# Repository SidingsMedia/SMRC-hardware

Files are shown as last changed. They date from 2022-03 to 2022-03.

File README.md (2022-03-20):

<!-- 
SPDX-FileCopyrightText: Copyright (c) 2021 Matthew Nickson 

SPDX-License-Identifier: MIT
-->
# Hardware
      

This repository contains all of the schematics and PCB files for Sidings
Media Railway Controller. 

## Main Control Board

This is the main component of the SMRC system. It provides a bridge
between the control nodes and the user as well as handling all of the
railway control logic.

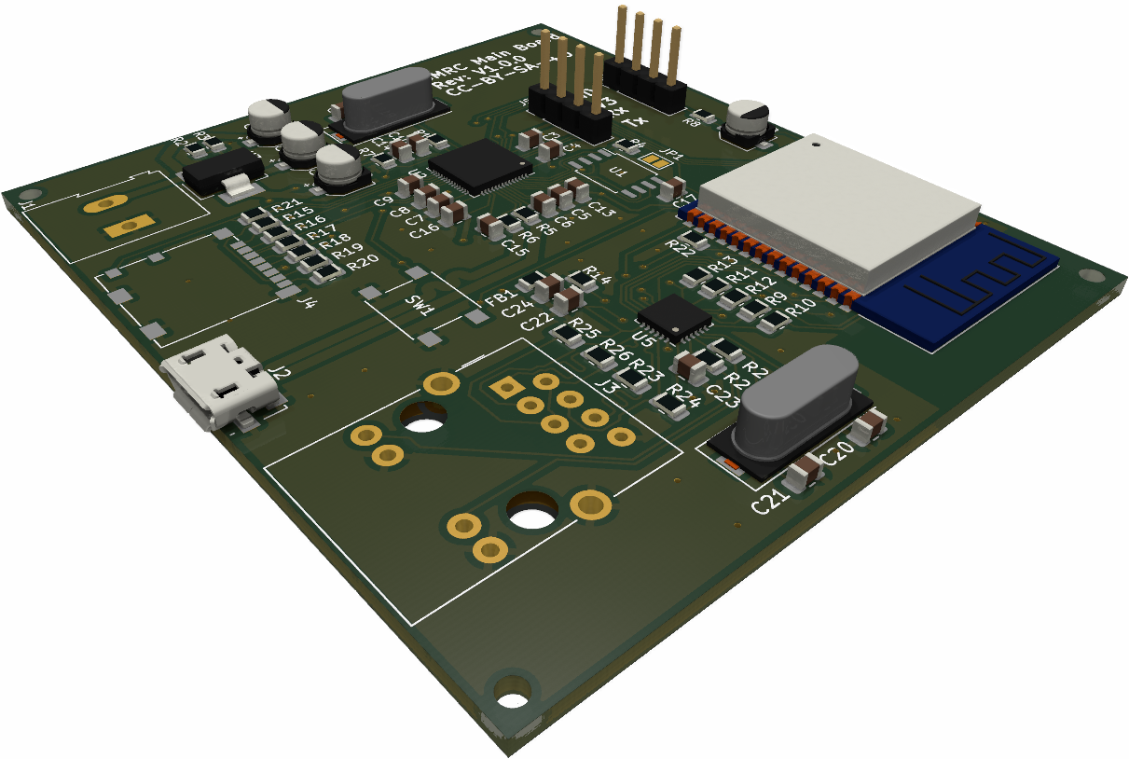
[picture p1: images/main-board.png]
3D render of main control PCB


## Speed Control Board

This is one of the nodes that helps to control the railway. It provides
power and controls the speed of a train on the tracks

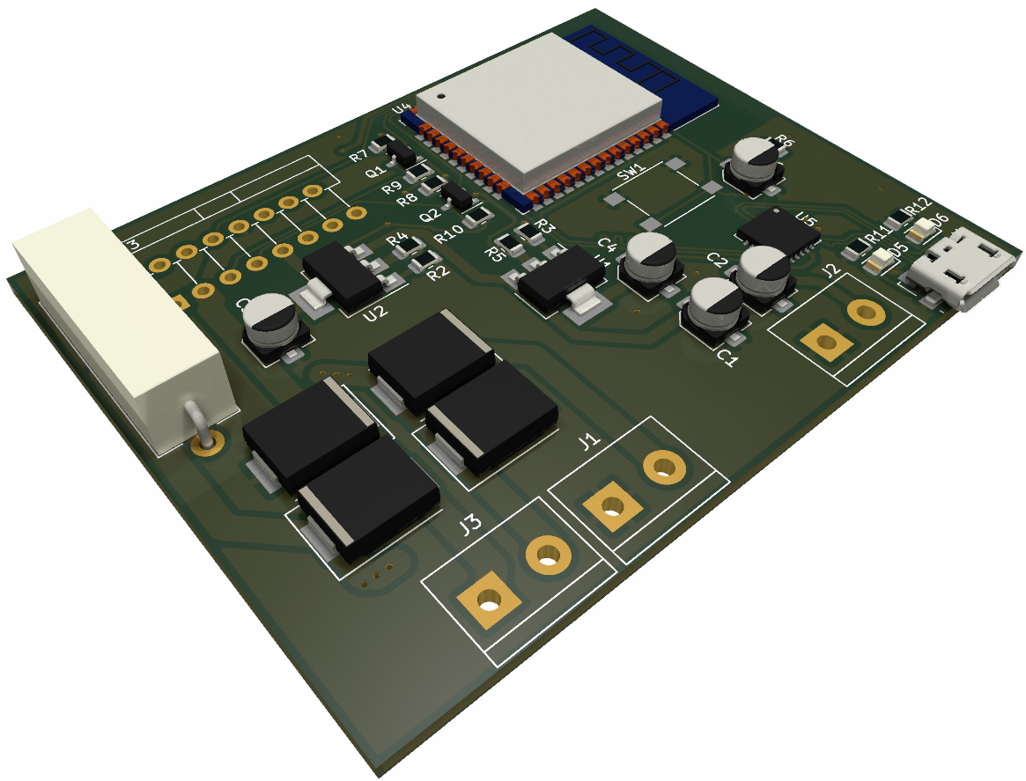
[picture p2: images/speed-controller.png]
3D render of speed control PCB


## Relay Board

This node controls isolation sections in your track allowing for
multiple trains to be on the same line without having to use DCC. It has
8 channels allowing for up to 8 seperate isolation sections to be
controlled from one speed controller.

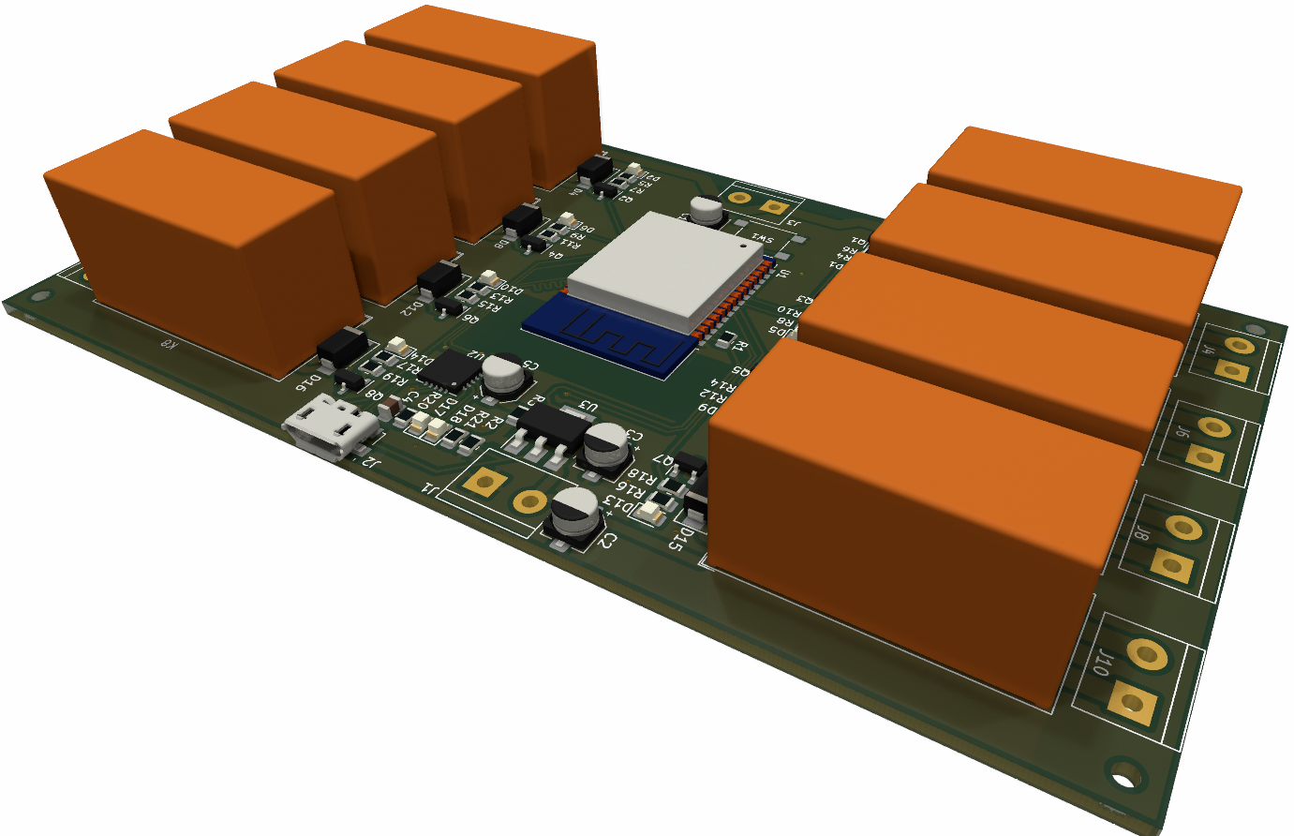
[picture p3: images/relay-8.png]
3D render of 8 channel relay PCB


# Licence
This repo uses the [REUSE](https://reuse.software) standard in order to communicate the correct licence for the file. For those unfamiliar with the standard the licence for each file can be found in one of three places. The licence will either be in a comment block at the top of the file, in a `.license` file with the same name as the file, or in the dep5 file located in the `.reuse` directory. If you are unsure of the licencing terms please contact [contact@sidingsmedia.com](mailto:contact@sidingsmedia.com?subject=SMRC%20Licence). All files committed to this repo must contain valid licencing information or the pull request can not be accepted.

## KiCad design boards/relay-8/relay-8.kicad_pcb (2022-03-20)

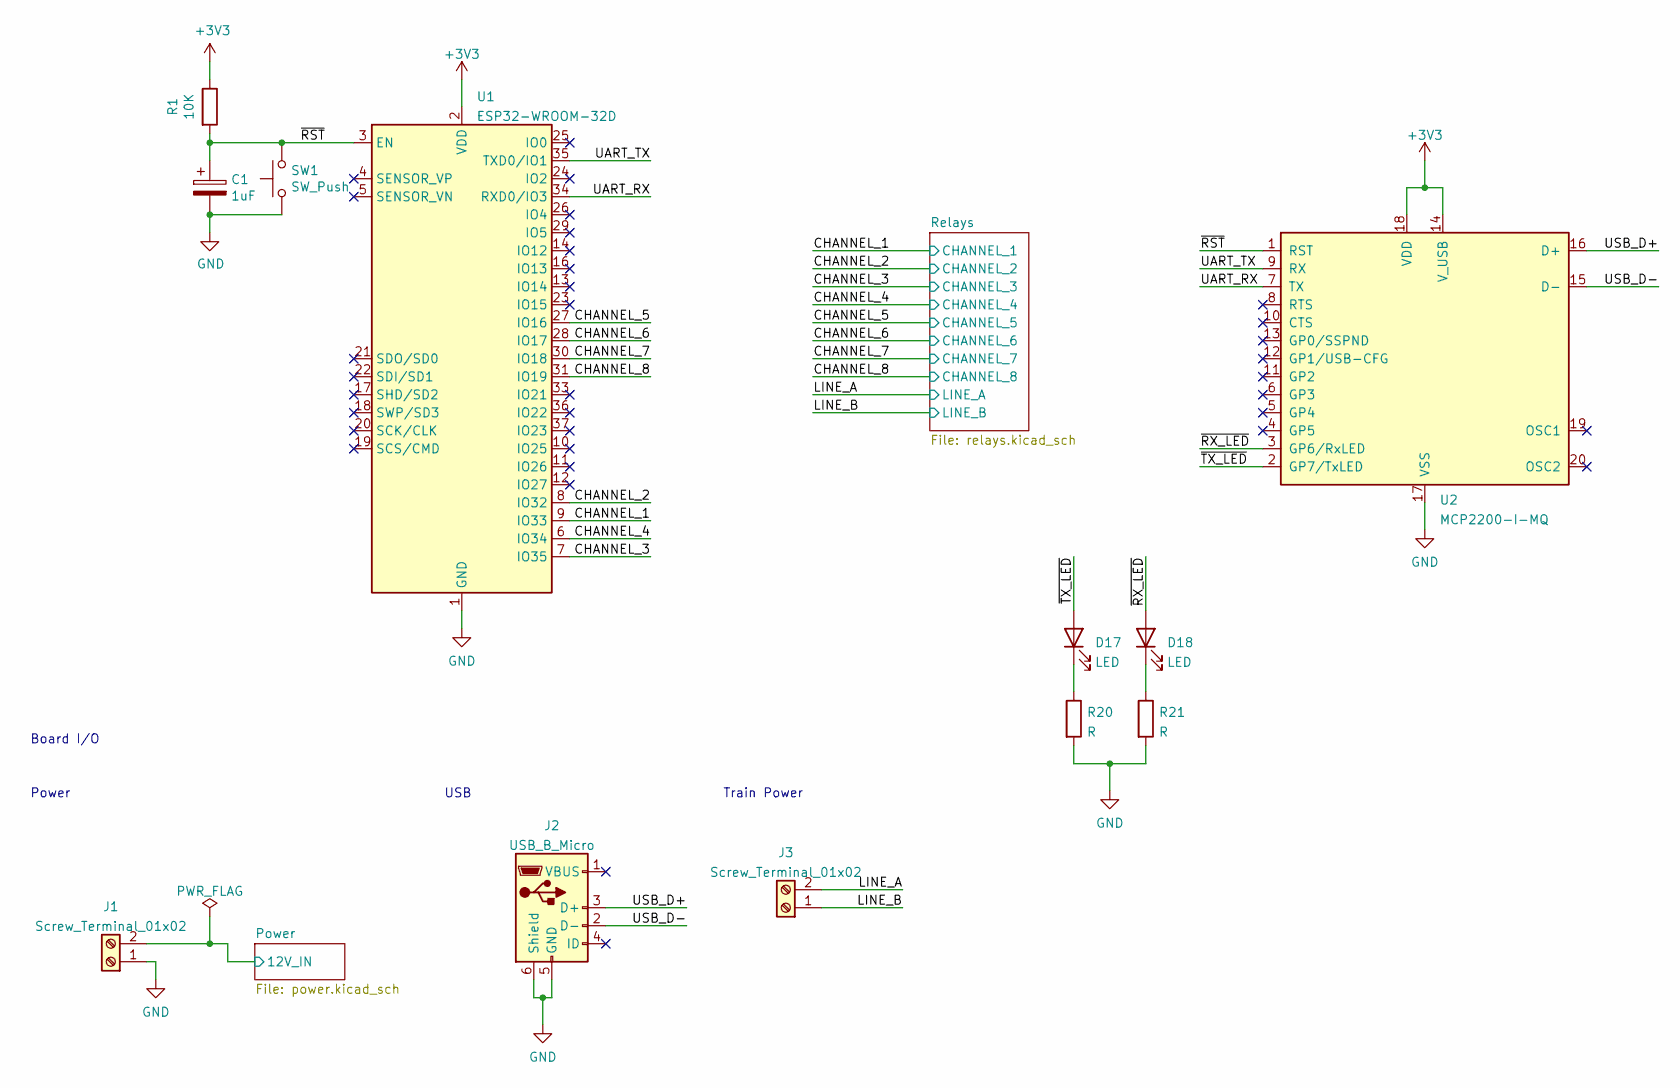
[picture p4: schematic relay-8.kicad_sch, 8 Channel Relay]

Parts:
C1: 1uF; CP_Elec_4x3
D17, D18: LED; LED_0805_2012Metric
J1, J3: Screw_Terminal_01x02; TerminalBlock_bornier-2_P5.08mm
J2: USB_B_Micro; USB_Micro-B_Molex_47346-0001
R1: 10K; R_0805_2012Metric
R20, R21: R; R_0805_2012Metric
SW1: SW_Push; SW_Push_1P1T_NO_6x6mm_H9.5mm
U1: ESP32-WROOM-32D; ESP32-WROOM-32
U2: MCP2200-I-MQ; QFN-20-1EP_5x5mm_P0.65mm_EP3.35x3.35mm

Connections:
+3V3: R1.1, U1.2 (VDD), U2.14 (V_USB), U2.18 (VDD); also elsewhere on the board
+12V: J1.2; also elsewhere on the board
/CHANNEL_1: U1.9 (IO33); also elsewhere on the board
/CHANNEL_2: U1.8 (IO32); also elsewhere on the board
/CHANNEL_3: U1.7 (IO35); also elsewhere on the board
/CHANNEL_4: U1.6 (IO34); also elsewhere on the board
/CHANNEL_5: U1.27 (IO16); also elsewhere on the board
/CHANNEL_6: U1.28 (IO17); also elsewhere on the board
/CHANNEL_7: U1.30 (IO18); also elsewhere on the board
/CHANNEL_8: U1.31 (IO19); also elsewhere on the board
/LINE_A: J3.2; also elsewhere on the board
/LINE_B: J3.1; also elsewhere on the board
/UART_RX: U1.34 (RXD0/IO3), U2.7 (TX)
/UART_TX: U1.35 (TXD0/IO1), U2.9 (RX)
/USB_D+: J2.3 (D+), U2.16 (D+)
/USB_D-: J2.2 (D-), U2.15 (D-)
/~RST: C1.1, R1.2, SW1.2, U1.3 (EN), U2.1 (RST)
/~RX_LED: D18.2 (A), U2.3 (GP6/RxLED)
/~TX_LED: D17.2 (A), U2.2 (GP7/TxLED)
GND: C1.2, J1.1, J2.5 (GND), J2.6 (Shield), R20.2, R21.2, SW1.1, U1.1 (GND), U1.15 (GND), U1.38 (GND), U1.39 (GND), U2.17 (VSS); also elsewhere on the board
unnamed: D17.1 (K), R20.1
unnamed: D18.1 (K), R21.1

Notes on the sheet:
Train Power
Board I/O
Power
USB

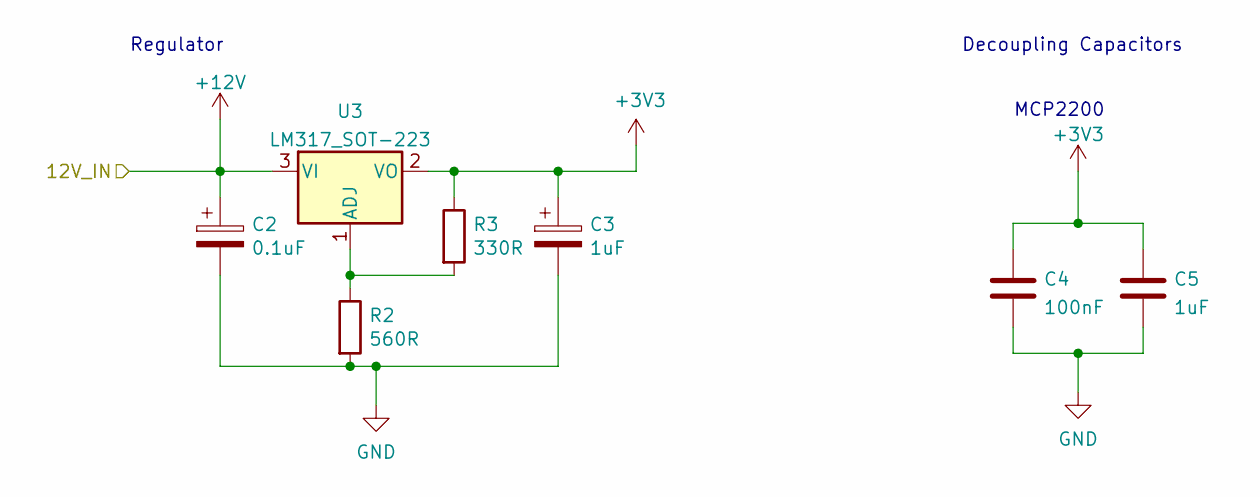
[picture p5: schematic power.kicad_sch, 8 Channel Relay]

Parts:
C2: 0.1uF; CP_Elec_4x3
C3, C5: 1uF; CP_Elec_4x3
C4: 100nF; C_0805_2012Metric
R2: 560R; R_0805_2012Metric
R3: 330R; R_0805_2012Metric
U3: LM317_SOT-223; SOT-223-3_TabPin2

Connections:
+3V3: C3.1, C4.1, C5.1, R3.1, U3.2 (VO); also elsewhere on the board
+12V: C2.1, U3.3 (VI); also elsewhere on the board
GND: C2.2, C3.2, C4.2, C5.2, R2.2; also elsewhere on the board
unnamed: R2.1, R3.2, U3.1 (ADJ)

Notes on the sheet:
Regulator
Decoupling Capacitors
MCP2200

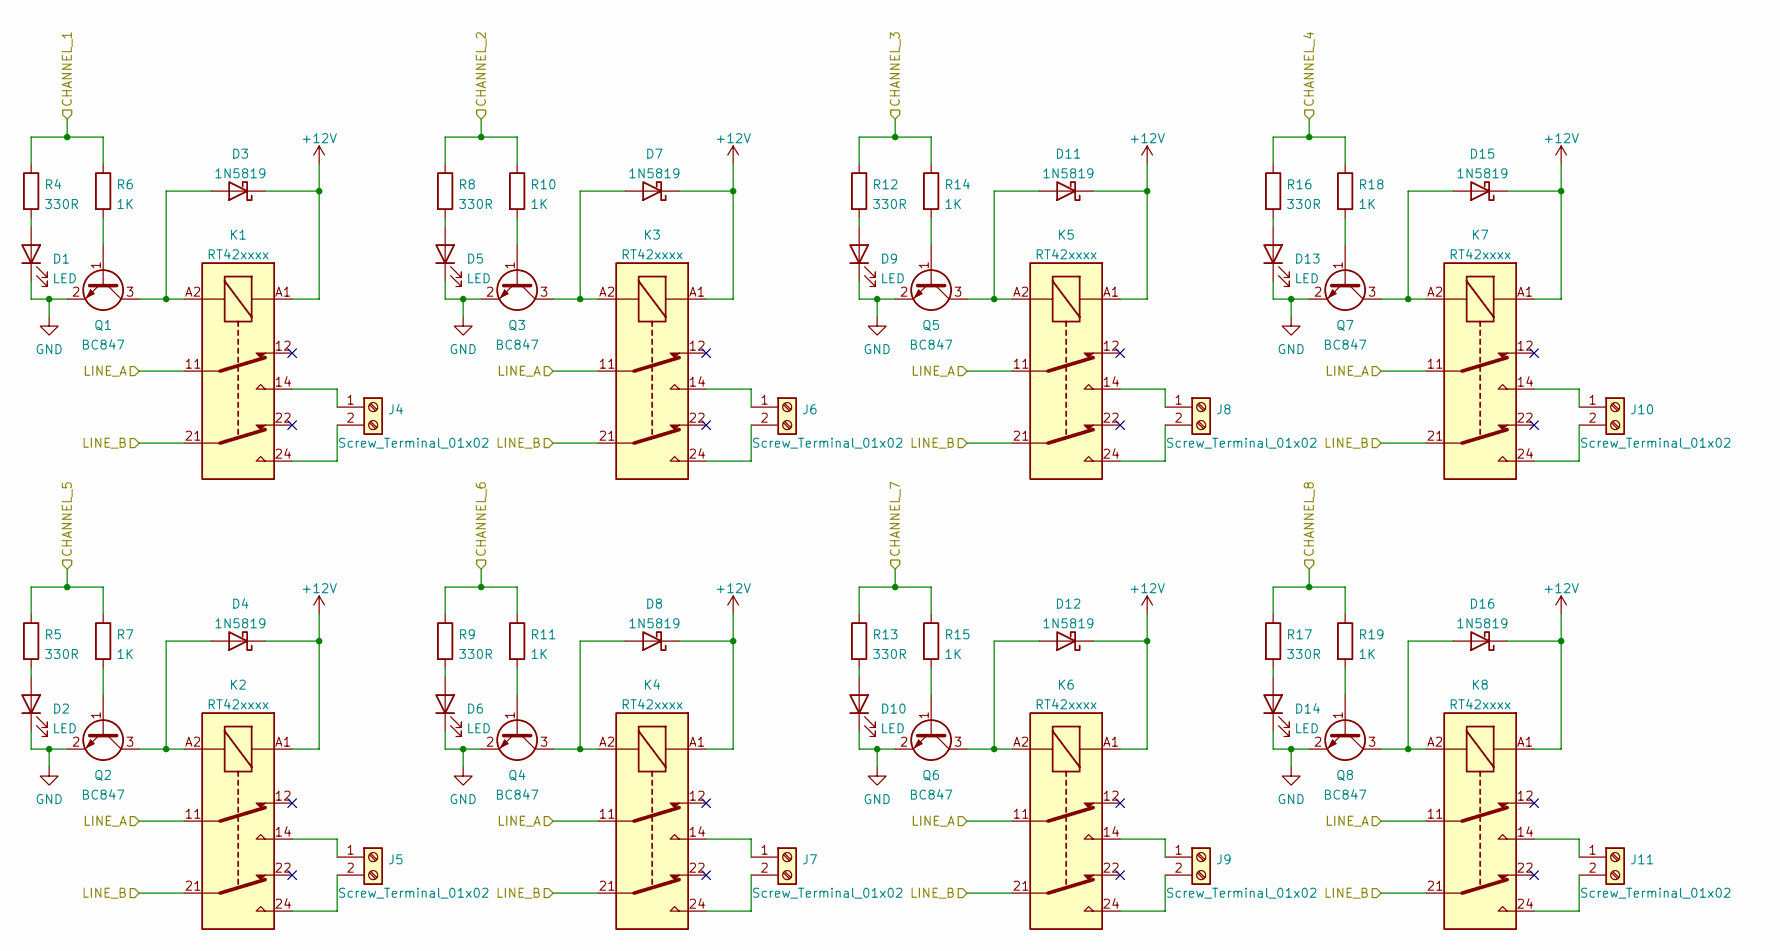
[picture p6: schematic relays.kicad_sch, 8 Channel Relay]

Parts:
D1, D2, D5, D6, D9, D10, D13, D14: LED; LED_0805_2012Metric
D3, D4, D7, D8, D11, D12, D15, D16: 1N5819; D_SMA
J4, J5, J6, J7, J8, J9, J10, J11: Screw_Terminal_01x02; TerminalBlock_bornier-2_P5.08mm
K1, K2, K3, K4, K5, K6, K7, K8: RT42xxxx; Relay_DPDT_Schrack-RT2-FormC_RM5mm
Q1, Q2, Q3, Q4, Q5, Q6, Q7, Q8: BC847; SOT-23
R4, R5, R8, R9, R12, R13, R16, R17: 330R; R_0805_2012Metric
R6, R7, R10, R11, R14, R15, R18, R19: 1K; R_0805_2012Metric

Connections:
+12V: D3.1 (K), D4.1 (K), D7.1 (K), D8.1 (K), D11.1 (K), D12.1 (K), D15.1 (K), D16.1 (K), K1.A1, K2.A1, K3.A1, K4.A1, K5.A1, K6.A1, K7.A1, K8.A1; also elsewhere on the board
/CHANNEL_1: R4.1, R6.1; also elsewhere on the board
/CHANNEL_2: R8.1, R10.1; also elsewhere on the board
/CHANNEL_3: R12.1, R14.1; also elsewhere on the board
/CHANNEL_4: R16.1, R18.1; also elsewhere on the board
/CHANNEL_5: R5.1, R7.1; also elsewhere on the board
/CHANNEL_6: R9.1, R11.1; also elsewhere on the board
/CHANNEL_7: R13.1, R15.1; also elsewhere on the board
/CHANNEL_8: R17.1, R19.1; also elsewhere on the board
/LINE_A: K1.11, K2.11, K3.11, K4.11, K5.11, K6.11, K7.11, K8.11; also elsewhere on the board
/LINE_B: K1.21, K2.21, K3.21, K4.21, K5.21, K6.21, K7.21, K8.21; also elsewhere on the board
GND: D1.1 (K), D2.1 (K), D5.1 (K), D6.1 (K), D9.1 (K), D10.1 (K), D13.1 (K), D14.1 (K), Q1.2 (E), Q2.2 (E), Q3.2 (E), Q4.2 (E), Q5.2 (E), Q6.2 (E), Q7.2 (E), Q8.2 (E); also elsewhere on the board
unnamed: D1.2 (A), R4.2
unnamed: D2.2 (A), R5.2
unnamed: D3.2 (A), K1.A2, Q1.3 (C)
unnamed: D4.2 (A), K2.A2, Q2.3 (C)
unnamed: D5.2 (A), R8.2
unnamed: D6.2 (A), R9.2
unnamed: D7.2 (A), K3.A2, Q3.3 (C)
unnamed: D8.2 (A), K4.A2, Q4.3 (C)
unnamed: D9.2 (A), R12.2
unnamed: D10.2 (A), R13.2
unnamed: D11.2 (A), K5.A2, Q5.3 (C)
unnamed: D12.2 (A), K6.A2, Q6.3 (C)
unnamed: D13.2 (A), R16.2
unnamed: D14.2 (A), R17.2
unnamed: D15.2 (A), K7.A2, Q7.3 (C)
unnamed: D16.2 (A), K8.A2, Q8.3 (C)
unnamed: J4.1, K1.14
unnamed: J4.2, K1.24
unnamed: J5.1, K2.14
unnamed: J5.2, K2.24
unnamed: J6.1, K3.14
unnamed: J6.2, K3.24
unnamed: J7.1, K4.14
unnamed: J7.2, K4.24
unnamed: J8.1, K5.14
unnamed: J8.2, K5.24
unnamed: J9.1, K6.14
unnamed: J9.2, K6.24
unnamed: J10.1, K7.14
unnamed: J10.2, K7.24
unnamed: J11.1, K8.14
unnamed: J11.2, K8.24
unnamed: Q1.1 (B), R6.2
unnamed: Q2.1 (B), R7.2
unnamed: Q3.1 (B), R10.2
unnamed: Q4.1 (B), R11.2
unnamed: Q5.1 (B), R14.2
unnamed: Q6.1 (B), R15.2
unnamed: Q7.1 (B), R18.2
unnamed: Q8.1 (B), R19.2

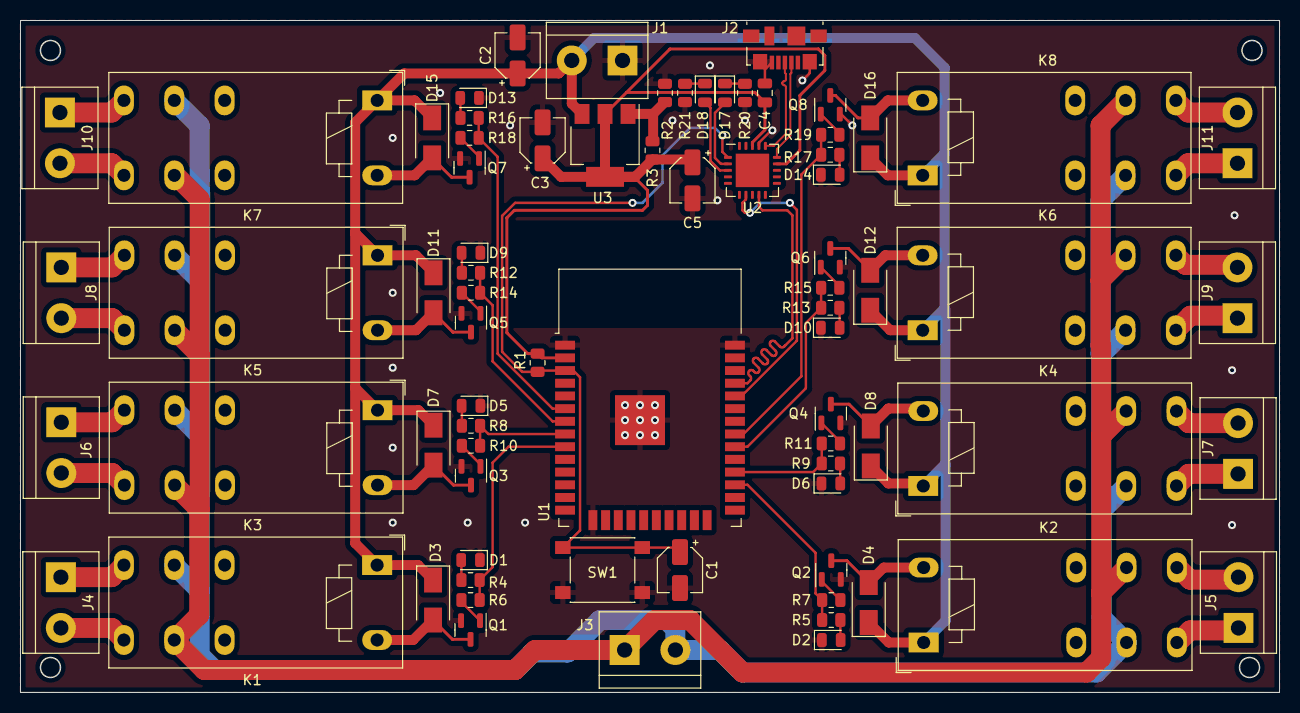
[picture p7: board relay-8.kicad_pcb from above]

Board: 2 copper layers, 126.0 x 67.2 mm, 75 parts (0 on the bottom side), 63 nets.

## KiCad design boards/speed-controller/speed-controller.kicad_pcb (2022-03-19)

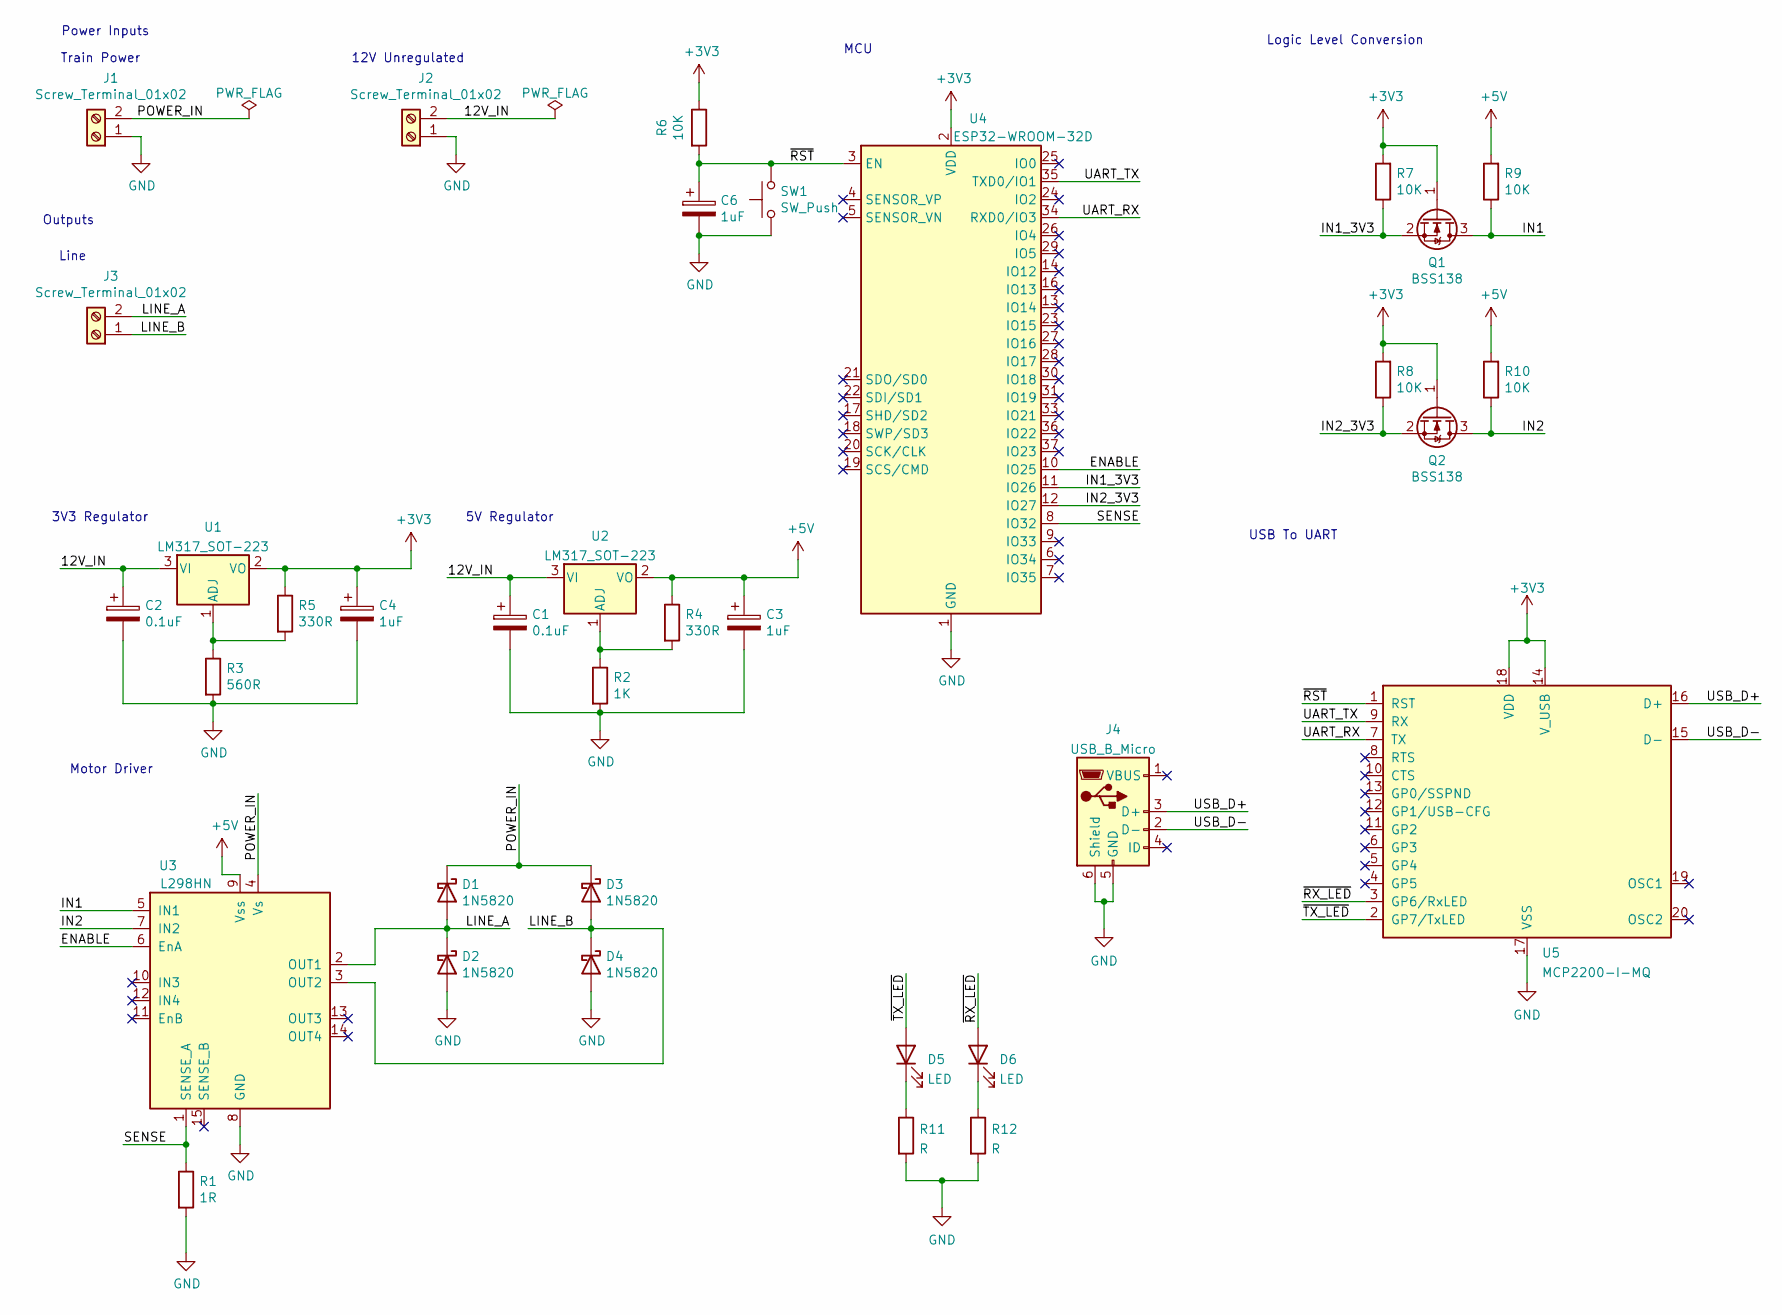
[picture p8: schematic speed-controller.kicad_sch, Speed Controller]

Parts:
C1, C2: 0.1uF; CP_Elec_4x3
C3, C4, C6: 1uF; CP_Elec_4x3
D1, D2, D3, D4: 1N5820; D_SMC
D5, D6: LED; LED_0805_2012Metric
J1, J2, J3: Screw_Terminal_01x02; TerminalBlock_bornier-2_P5.08mm
J4: USB_B_Micro; USB_Micro-B_Molex_47346-0001
Q1, Q2: BSS138; SOT-23
R1: 1R; R_Axial_Power_L20.0mm_W6.4mm_P22.40mm
R2: 1K; R_0805_2012Metric
R3: 560R; R_0805_2012Metric
R4, R5: 330R; R_0805_2012Metric
R6, R7, R8, R9, R10: 10K; R_0805_2012Metric
R11, R12: R; R_0805_2012Metric
SW1: SW_Push; SW_Push_1P1T_NO_6x6mm_H9.5mm
U1, U2: LM317_SOT-223; SOT-223-3_TabPin2
U3: L298HN; TO-220-15_P2.54x2.54mm_StaggerOdd_Lead4.58mm_Vertical
U4: ESP32-WROOM-32D; ESP32-WROOM-32
U5: MCP2200-I-MQ; QFN-20-1EP_5x5mm_P0.65mm_EP3.35x3.35mm

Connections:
+3V3: C4.1, Q1.1 (G), Q2.1 (G), R5.1, R6.1, R7.2, R8.2, U1.2 (VO), U4.2 (VDD), U5.14 (V_USB), U5.18 (VDD)
+5V: C3.1, R4.1, R9.2, R10.2, U2.2 (VO), U3.9 (Vss)
/12V_IN: C1.1, C2.1, J2.2, U1.3 (VI), U2.3 (VI)
/ENABLE: U3.6 (EnA), U4.10 (IO25)
/IN1: Q1.3 (D), R9.1, U3.5 (IN1)
/IN1_3V3: Q1.2 (S), R7.1, U4.11 (IO26)
/IN2: Q2.3 (D), R10.1, U3.7 (IN2)
/IN2_3V3: Q2.2 (S), R8.1, U4.12 (IO27)
/LINE_A: D1.2 (A), D2.1 (K), J3.2, U3.2 (OUT1)
/LINE_B: D3.2 (A), D4.1 (K), J3.1, U3.3 (OUT2)
/POWER_IN: D1.1 (K), D3.1 (K), J1.2, U3.4 (Vs)
/SENSE: R1.1, U3.1 (SENSE_A), U4.8 (IO32)
/UART_RX: U4.34 (RXD0/IO3), U5.7 (TX)
/UART_TX: U4.35 (TXD0/IO1), U5.9 (RX)
/USB_D+: J4.3 (D+), U5.16 (D+)
/USB_D-: J4.2 (D-), U5.15 (D-)
/~RST: C6.1, R6.2, SW1.2, U4.3 (EN), U5.1 (RST)
/~RX_LED: D6.2 (A), U5.3 (GP6/RxLED)
/~TX_LED: D5.2 (A), U5.2 (GP7/TxLED)
GND: C1.2, C2.2, C3.2, C4.2, C6.2, D2.2 (A), D4.2 (A), J1.1, J2.1, J4.5 (GND), J4.6 (Shield), R1.2, R2.2, R3.2, R11.2, R12.2, SW1.1, U3.8 (GND), U4.1 (GND), U4.15 (GND), U4.38 (GND), U4.39 (GND), U5.17 (VSS)
unnamed: D5.1 (K), R11.1
unnamed: D6.1 (K), R12.1
unnamed: R2.1, R4.2, U2.1 (ADJ)
unnamed: R3.1, R5.2, U1.1 (ADJ)

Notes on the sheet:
Train Power
MCU
12V Unregulated
Logic Level Conversion
5V Regulator
Motor Driver
USB To UART
3V3 Regulator
Power Inputs
Outputs
Line

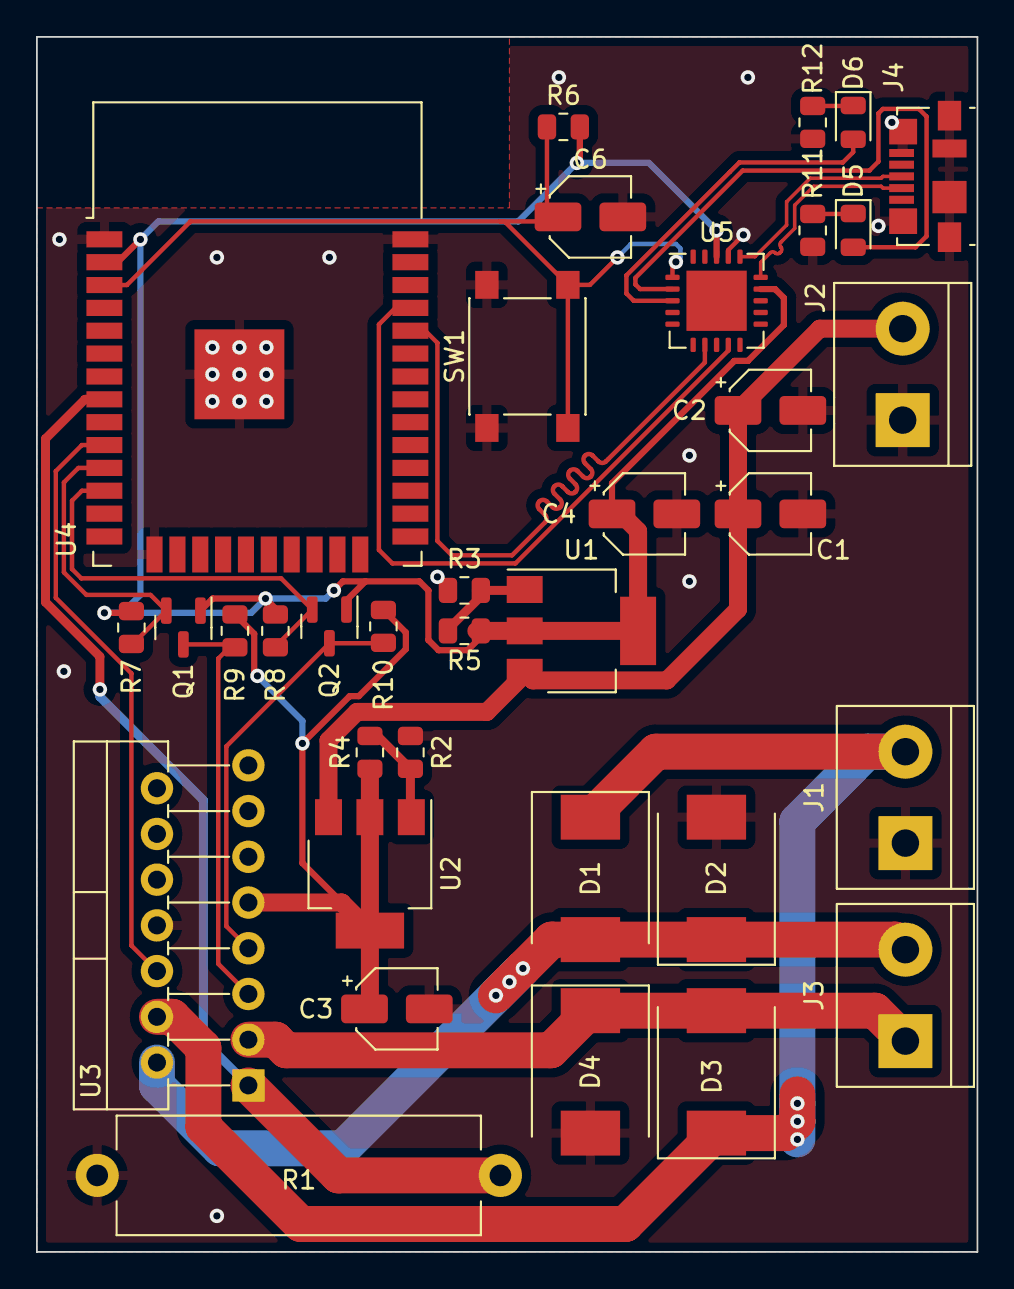
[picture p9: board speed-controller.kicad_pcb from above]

Board: 2 copper layers, 52.2 x 67.5 mm, 35 parts (0 on the bottom side), 24 nets.

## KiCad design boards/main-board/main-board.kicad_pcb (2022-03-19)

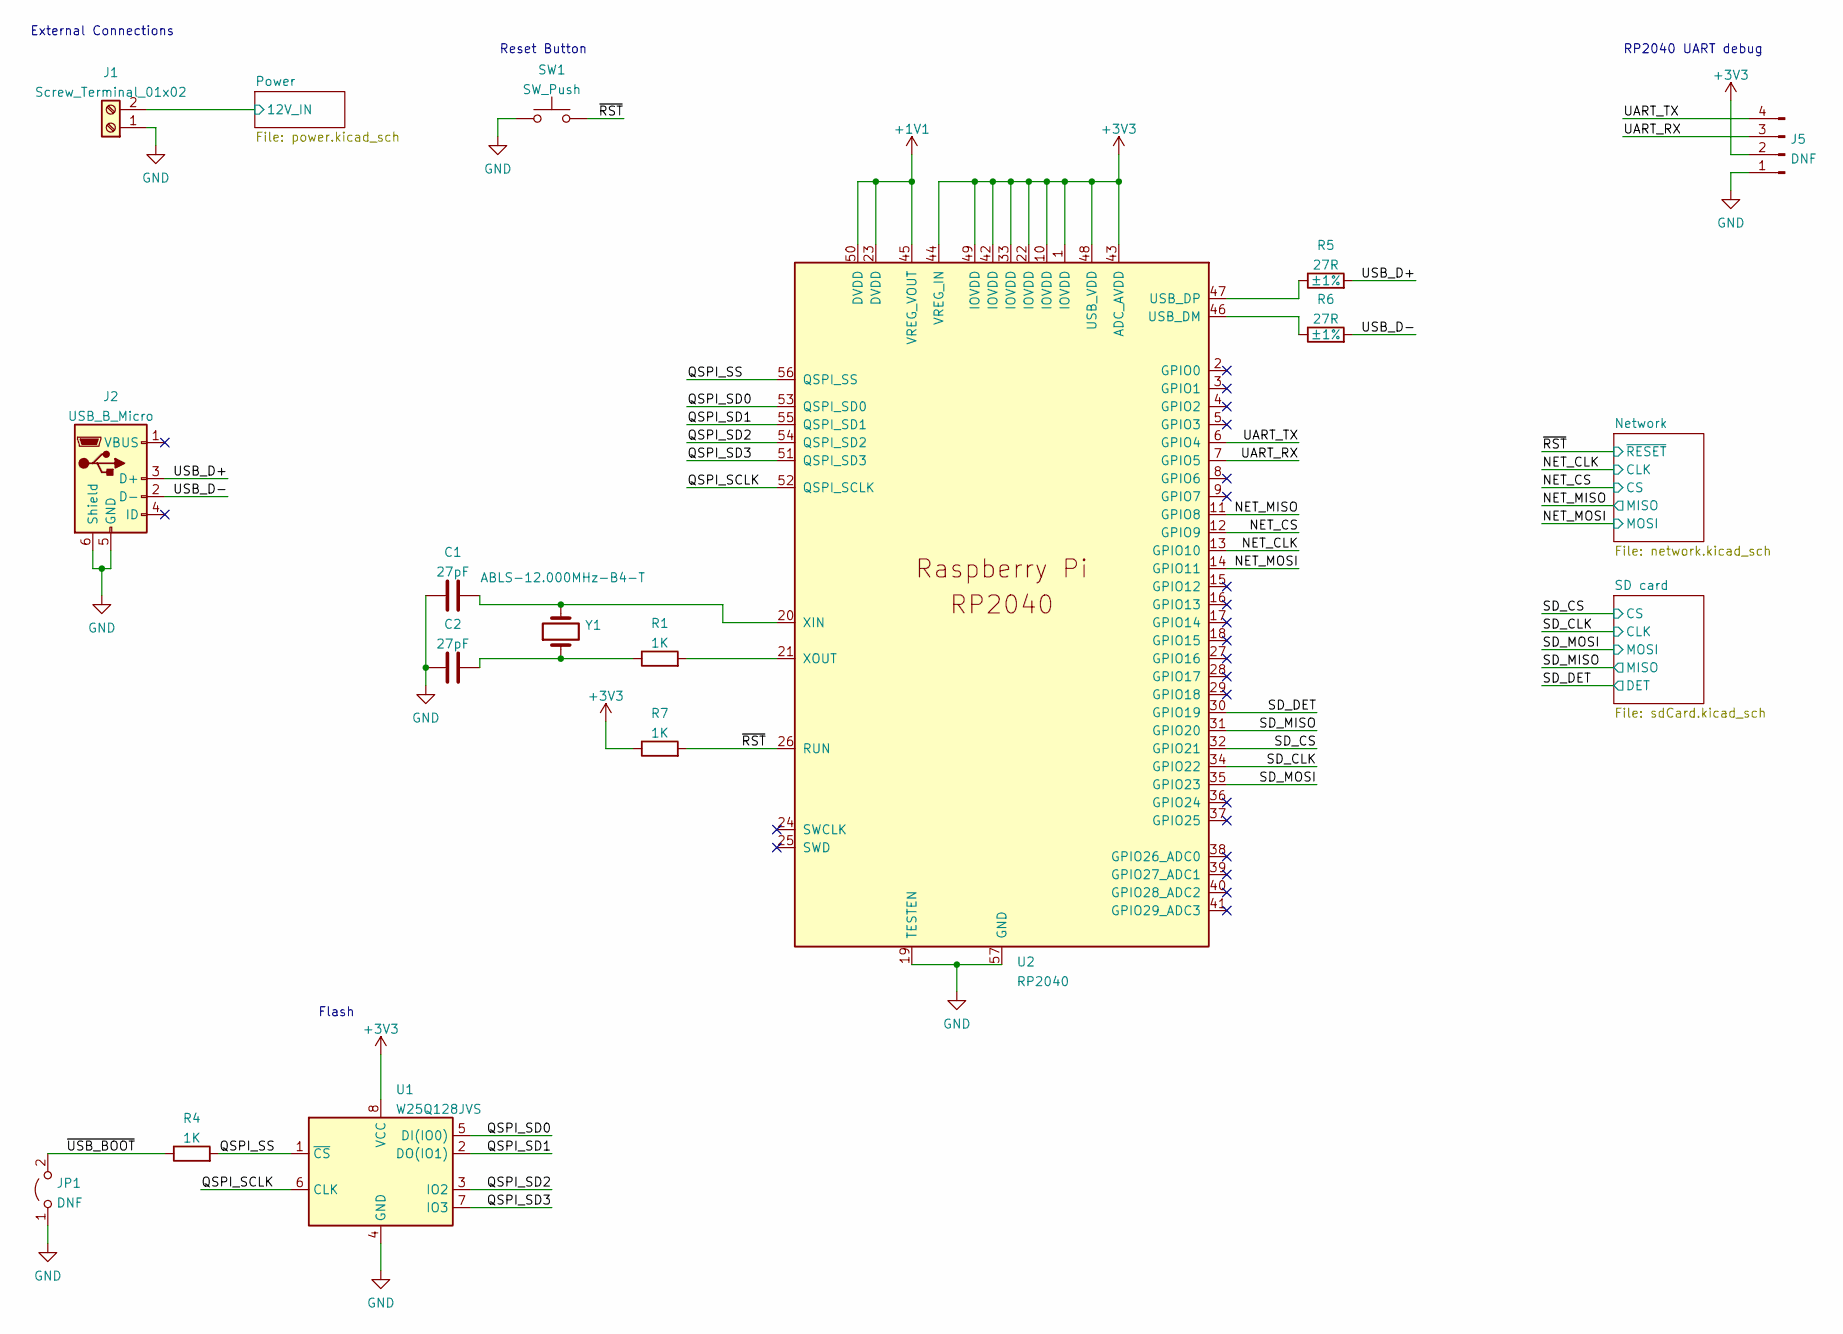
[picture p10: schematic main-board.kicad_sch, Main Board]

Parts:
C1, C2: 27pF; C_0805_2012Metric
J1: Screw_Terminal_01x02; TerminalBlock_Altech_AK300-2_P5.00mm
J2: USB_B_Micro; USB_Micro-B_Molex_47346-0001
J5: DNF; PinHeader_1x04_P2.54mm_Vertical
JP1: DNF; SolderJumper-2_P1.3mm_Open_Pad1.0x1.5mm
R1, R4, R7: 1K; R_0805_2012Metric
R5, R6: 27R; R_0805_2012Metric; Tolerance ±1%
SW1: SW_Push; SW_Push_1P1T_NO_6x6mm_H9.5mm
U1: W25Q128JVS; SOIC-8_5.23x5.23mm_P1.27mm
U2: RP2040; RP2040-QFN-56
Y1: ABLS-12.000MHz-B4-T; Crystal_SMD_HC49-SD

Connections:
+1V1: U2.23 (DVDD), U2.45 (VREG_VOUT), U2.50 (DVDD); also elsewhere on the board
+3V3: J5.2, R7.1, U1.8 (VCC), U2.1 (IOVDD), U2.10 (IOVDD), U2.22 (IOVDD), U2.33 (IOVDD), U2.42 (IOVDD), U2.43 (ADC_AVDD), U2.44 (VREG_IN), U2.48 (USB_VDD), U2.49 (IOVDD); also elsewhere on the board
/NET_CLK: U2.13 (GPIO10); also elsewhere on the board
/NET_CS: U2.12 (GPIO9); also elsewhere on the board
/NET_MISO: U2.11 (GPIO8); also elsewhere on the board
/NET_MOSI: U2.14 (GPIO11); also elsewhere on the board
/Power/12V_IN: J1.2; also elsewhere on the board
/QSPI_SCLK: U1.6 (CLK), U2.52 (QSPI_SCLK)
/QSPI_SD0: U1.5 (DI(IO0)), U2.53 (QSPI_SD0)
/QSPI_SD1: U1.2 (DO(IO1)), U2.55 (QSPI_SD1)
/QSPI_SD2: U1.3 (IO2), U2.54 (QSPI_SD2)
/QSPI_SD3: U1.7 (IO3), U2.51 (QSPI_SD3)
/QSPI_SS: R4.2, U1.1 (~CS), U2.56 (QSPI_SS)
/SD_CLK: U2.34 (GPIO22); also elsewhere on the board
/SD_CS: U2.32 (GPIO21); also elsewhere on the board
/SD_DET: U2.30 (GPIO19); also elsewhere on the board
/SD_MISO: U2.31 (GPIO20); also elsewhere on the board
/SD_MOSI: U2.35 (GPIO23); also elsewhere on the board
/UART_RX: J5.3, U2.7 (GPIO5)
/UART_TX: J5.4, U2.6 (GPIO4)
/USB_D+: J2.3 (D+), R5.2
/USB_D-: J2.2 (D-), R6.2
/~RST: R7.2, SW1.2, U2.26 (RUN); also elsewhere on the board
/~USB_BOOT: JP1.2 (B), R4.1
GND: C1.1, C2.1, J1.1, J2.5 (GND), J2.6 (Shield), J5.1, JP1.1 (A), SW1.1, U1.4 (GND), U2.19 (TESTEN), U2.57 (GND); also elsewhere on the board
unnamed: C1.2, U2.20 (XIN), Y1.2
unnamed: C2.2, R1.1, Y1.1
unnamed: R1.2, U2.21 (XOUT)
unnamed: R5.1, U2.47 (USB_DP)
unnamed: R6.1, U2.46 (USB_DM)

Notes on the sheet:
External Connections
Reset Button
RP2040 UART debug
Flash

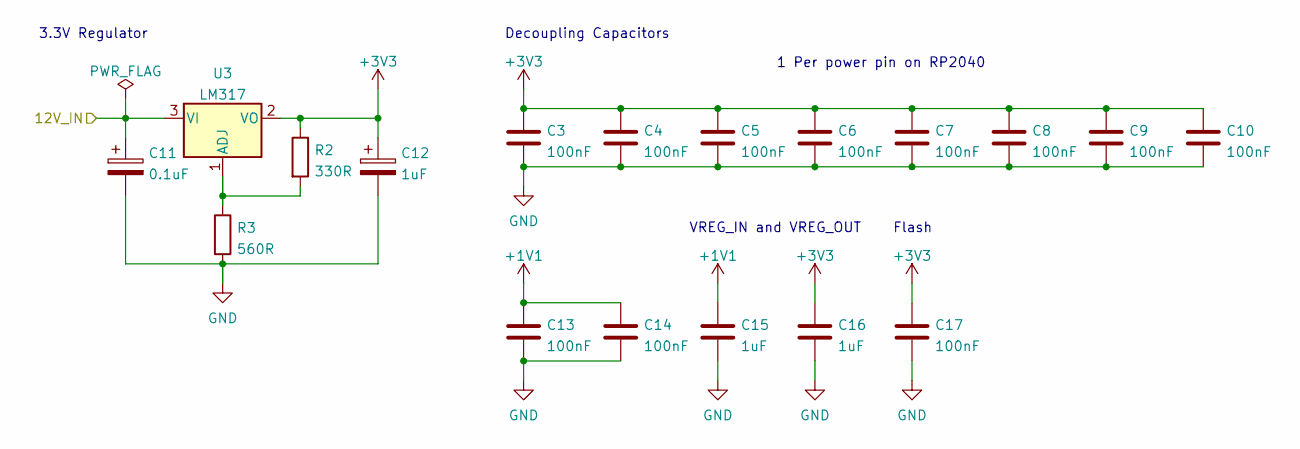
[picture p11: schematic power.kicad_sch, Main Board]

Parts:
C3, C4, C5, C6, C7, C8, C9, C10, C13, C14, C17: 100nF; C_0805_2012Metric
C11: 0.1uF; CP_Elec_4x3
C12: 1uF; CP_Elec_4x3
C15, C16: 1uF; C_0805_2012Metric
R2: 330R; R_0805_2012Metric
R3: 560R; R_0805_2012Metric
U3: LM317; SOT-223-3_TabPin2

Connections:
+1V1: C13.1, C14.1, C15.1; also elsewhere on the board
+3V3: C3.1, C4.1, C5.1, C6.1, C7.1, C8.1, C9.1, C10.1, C12.1, C16.1, C17.1, R2.1, U3.2 (VO); also elsewhere on the board
/Power/12V_IN: C11.1, U3.3 (VI); also elsewhere on the board
GND: C3.2, C4.2, C5.2, C6.2, C7.2, C8.2, C9.2, C10.2, C11.2, C12.2, C13.2, C14.2, C15.2, C16.2, C17.2, R3.2; also elsewhere on the board
unnamed: R2.2, R3.1, U3.1 (ADJ)

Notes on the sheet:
Decoupling Capacitors
VREG_IN and VREG_OUT
3.3V Regulator
Flash
1 Per power pin on RP2040

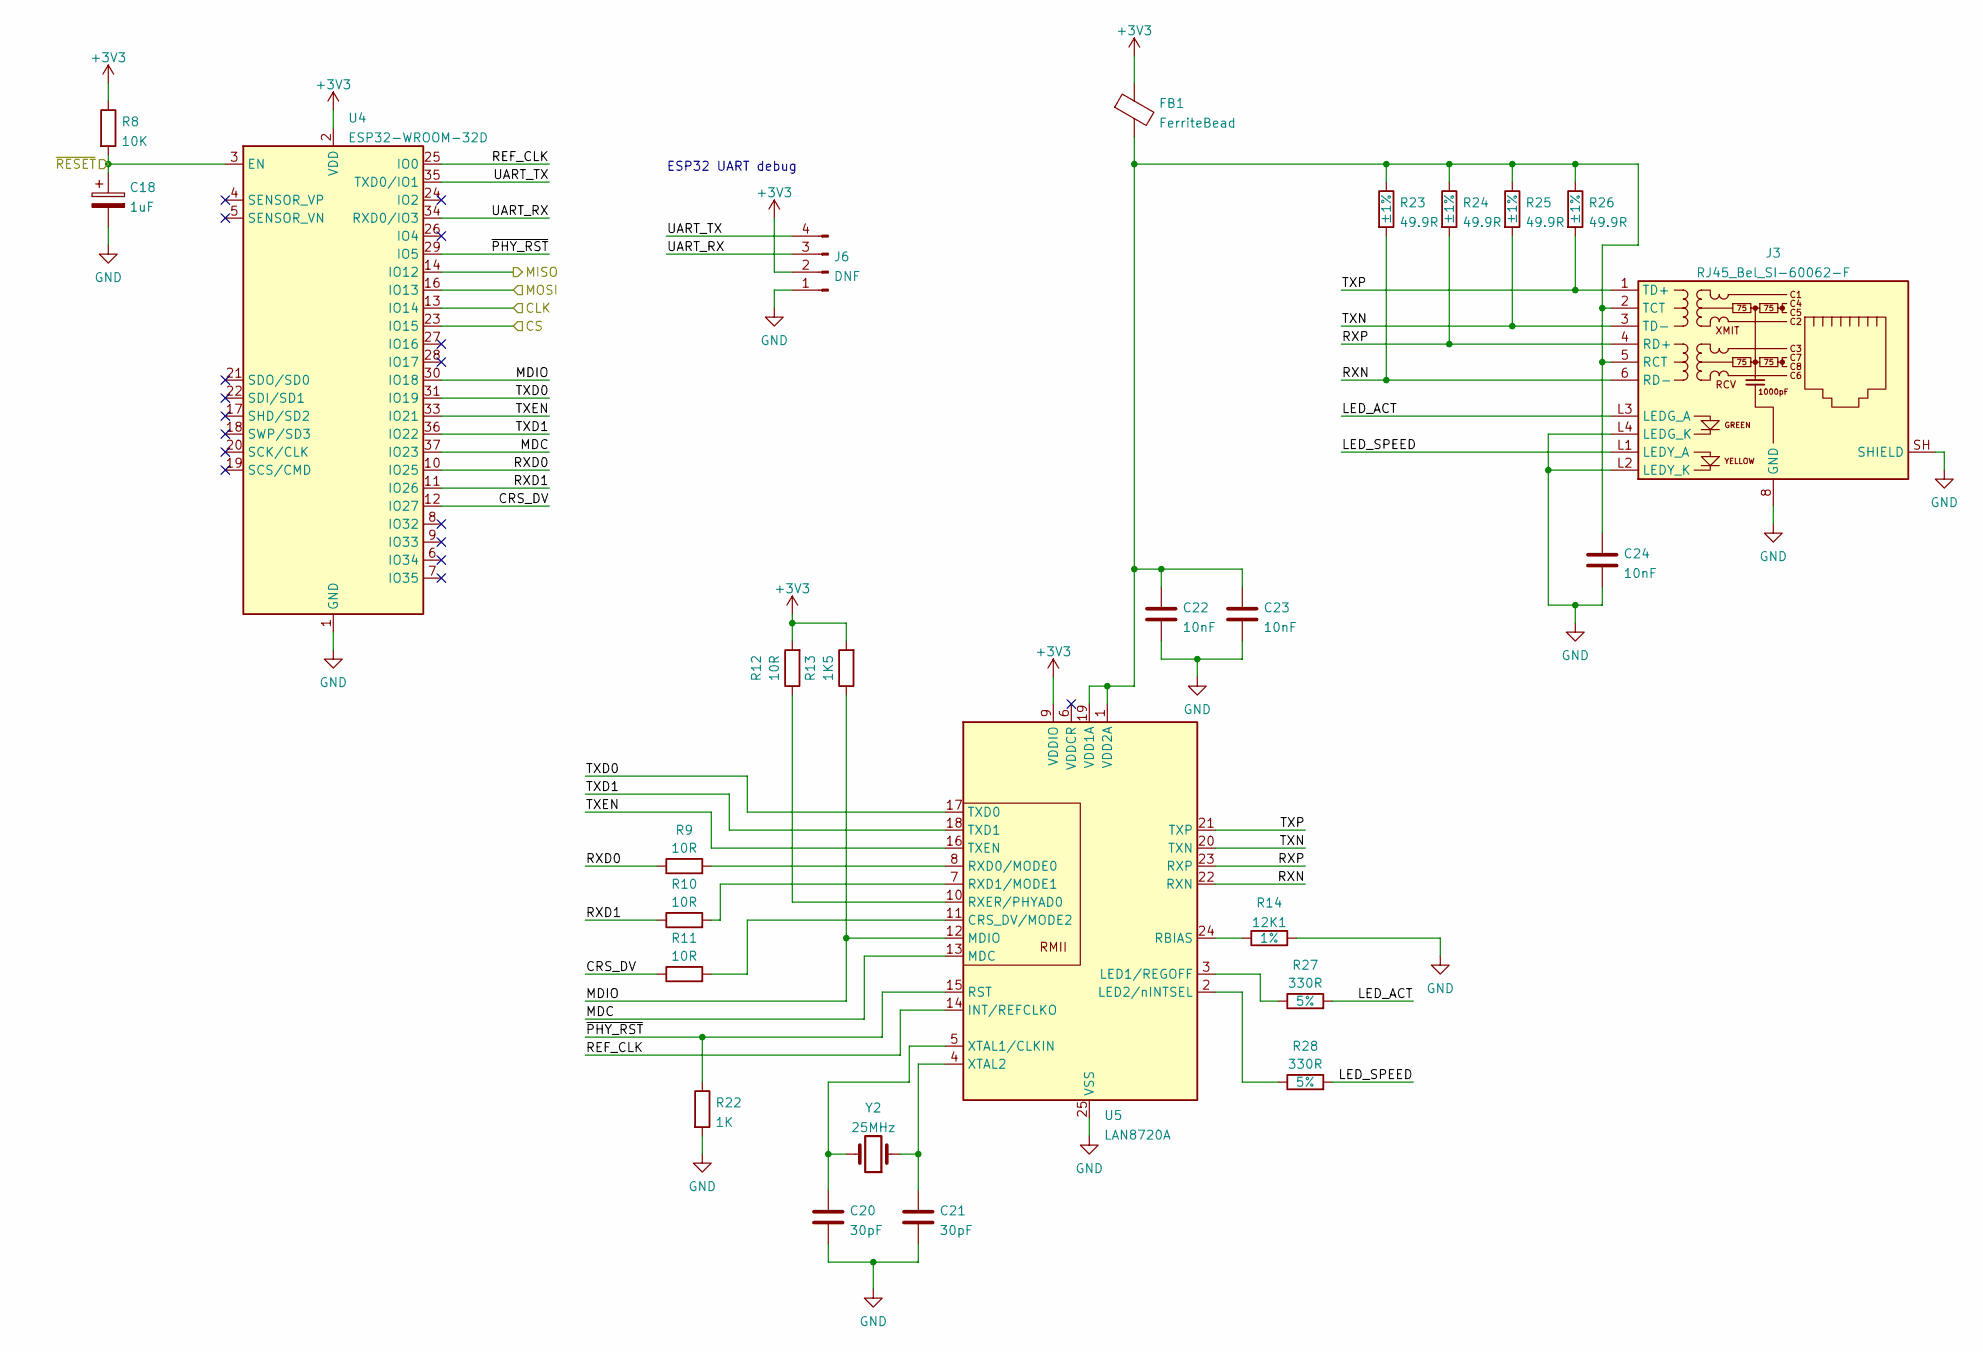
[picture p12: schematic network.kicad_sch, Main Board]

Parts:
C18: 1uF; CP_Elec_4x3
C20, C21: 30pF; C_0805_2012Metric
C22, C23, C24: 10nF; C_0805_2012Metric
FB1: FerriteBead; R_0805_2012Metric
J3: RJ45_Bel_SI-60062-F
J6: DNF; PinHeader_1x04_P2.54mm_Vertical
R8: 10K; R_0805_2012Metric
R9, R10, R11, R12: 10R; R_0805_2012Metric
R13: 1K5; R_0805_2012Metric
R14: 12K1; R_0805_2012Metric; Tolerance 1%
R22: 1K; R_0805_2012Metric
R23, R24, R25, R26: 49.9R; R_0805_2012Metric; Tolerance ±1%
R27, R28: 330R; R_0805_2012Metric; Tolerance 5%
U4: ESP32-WROOM-32D; ESP32-WROOM-32
U5: LAN8720A; QFN-24-1EP_4x4mm_P0.5mm_EP2.6x2.6mm
Y2: 25MHz; Crystal_SMD_HC49-SD

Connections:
+3V3: FB1.1, J6.2, R8.1, R12.2, R13.2, U4.2 (VDD), U5.9 (VDDIO); also elsewhere on the board
/NET_CLK: U4.13 (IO14); also elsewhere on the board
/NET_CS: U4.23 (IO15); also elsewhere on the board
/NET_MISO: U4.14 (IO12); also elsewhere on the board
/NET_MOSI: U4.16 (IO13); also elsewhere on the board
/Network/CRS_DV: R11.1, U4.12 (IO27)
/Network/LED_ACT: J3.L3 (LEDG_A), R27.2
/Network/LED_SPEED: J3.L1 (LEDY_A), R28.2
/Network/MDC: U4.37 (IO23), U5.13 (MDC)
/Network/MDIO: R13.1, U4.30 (IO18), U5.12 (MDIO)
/Network/REF_CLK: U4.25 (IO0), U5.14 (INT/REFCLKO)
/Network/RXD0: R9.1, U4.10 (IO25)
/Network/RXD1: R10.1, U4.11 (IO26)
/Network/RXN: J3.6 (RD-), R23.2, U5.22 (RXN)
/Network/RXP: J3.4 (RD+), R24.2, U5.23 (RXP)
/Network/TXD0: U4.31 (IO19), U5.17 (TXD0)
/Network/TXD1: U4.36 (IO22), U5.18 (TXD1)
/Network/TXEN: U4.33 (IO21), U5.16 (TXEN)
/Network/TXN: J3.3 (TD-), R25.2, U5.20 (TXN)
/Network/TXP: J3.1 (TD+), R26.2, U5.21 (TXP)
/Network/UART_RX: J6.3, U4.34 (RXD0/IO3)
/Network/UART_TX: J6.4, U4.35 (TXD0/IO1)
/Network/~PHY_RST: R22.1, U4.29 (IO5), U5.15 (RST)
/~RST: C18.1, R8.2, U4.3 (EN); also elsewhere on the board
GND: C18.2, C20.2, C21.2, C22.2, C23.2, C24.2, J3.8 (GND), J3.L2 (LEDY_K), J3.L4 (LEDG_K), J3.SH (SHIELD), J6.1, R14.2, R22.2, U4.1 (GND), U4.15 (GND), U4.38 (GND), U4.39 (GND), U5.25 (VSS); also elsewhere on the board
unnamed: C20.1, U5.5 (XTAL1/CLKIN), Y2.2
unnamed: C21.1, U5.4 (XTAL2), Y2.1
unnamed: C22.1, C23.1, C24.1, FB1.2, J3.2 (TCT), J3.5 (RCT), R23.1, R24.1, R25.1, R26.1, U5.1 (VDD2A), U5.19 (VDD1A)
unnamed: R9.2, U5.8 (RXD0/MODE0)
unnamed: R10.2, U5.7 (RXD1/MODE1)
unnamed: R11.2, U5.11 (CRS_DV/MODE2)
unnamed: R12.1, U5.10 (RXER/PHYAD0)
unnamed: R14.1, U5.24 (RBIAS)
unnamed: R27.1, U5.3 (LED1/REGOFF)
unnamed: R28.1, U5.2 (LED2/nINTSEL)

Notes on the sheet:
ESP32 UART debug

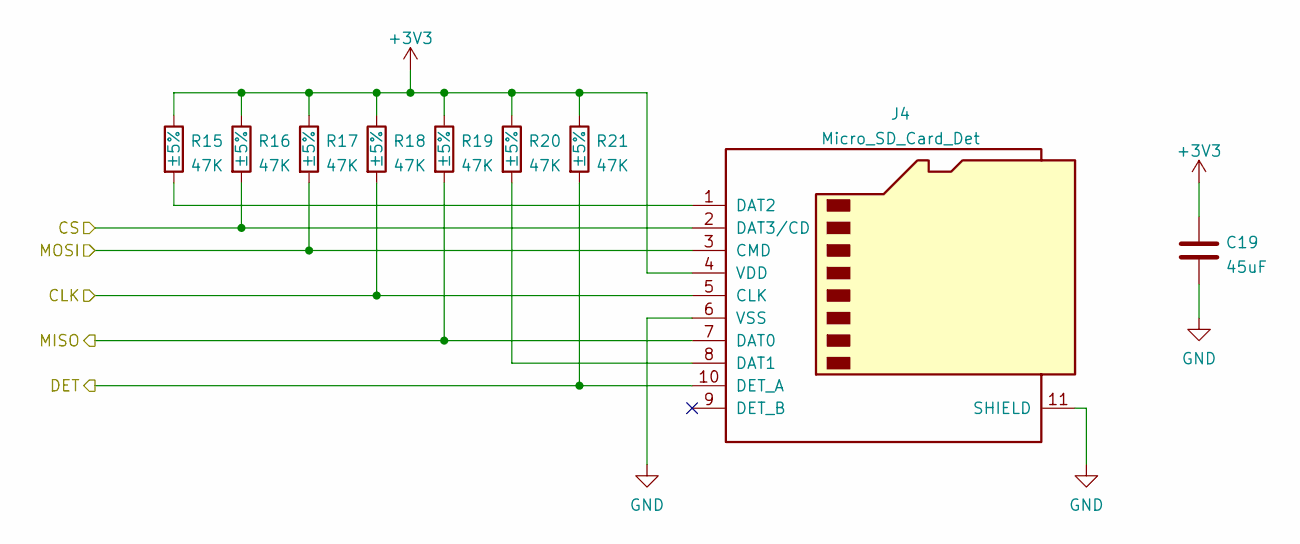
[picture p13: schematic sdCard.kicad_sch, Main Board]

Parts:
C19: 45uF; CP_Elec_4x3
J4: Micro_SD_Card_Det; microSD_HC_Molex_104031-0811
R15, R16, R17, R18, R19, R20, R21: 47K; R_0805_2012Metric; Tolerance ±5%

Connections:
+3V3: C19.1, J4.4 (VDD), R15.1, R16.1, R17.1, R18.1, R19.1, R20.1, R21.1; also elsewhere on the board
/SD_CLK: J4.5 (CLK), R18.2; also elsewhere on the board
/SD_CS: J4.2 (DAT3/CD), R16.2; also elsewhere on the board
/SD_DET: J4.10 (DET_A), R21.2; also elsewhere on the board
/SD_MISO: J4.7 (DAT0), R19.2; also elsewhere on the board
/SD_MOSI: J4.3 (CMD), R17.2; also elsewhere on the board
GND: C19.2, J4.6 (VSS), J4.11 (SHIELD); also elsewhere on the board
unnamed: J4.1 (DAT2), R15.2
unnamed: J4.8 (DAT1), R20.2

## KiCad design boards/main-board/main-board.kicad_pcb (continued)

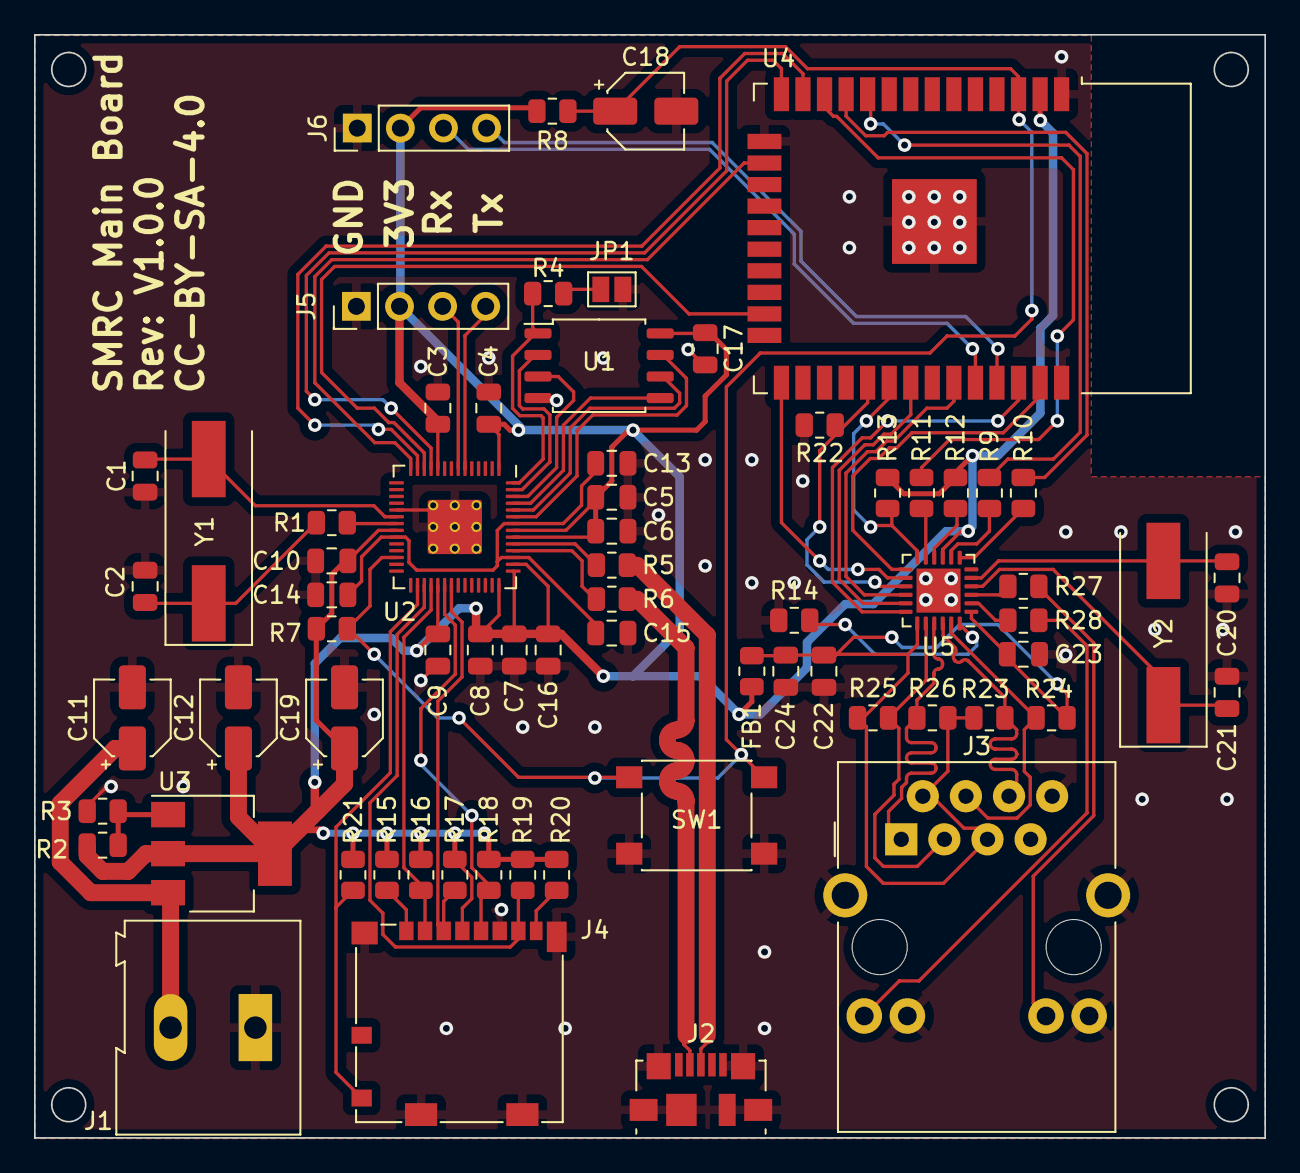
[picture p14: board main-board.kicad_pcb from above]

Board: 2 copper layers, 72.5 x 65.0 mm, 68 parts (0 on the bottom side), 61 nets.

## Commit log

2021-10-21 Added .gitignore
    Ignore rules have been added for kicad files as well as the vscode
    config directory.
2021-10-21 Added schematic style
    The style for the schematics as well as the licence file for it has been
    added. This file must be used to style all schematics in this repository
2021-10-22 Created initial KiCad project
    [speed-controller.kicad_pcb, speed-controller.sch]
2022-01-01 Added basic design
    [speed-controller.sch]
2022-01-01 Added component annotations
    [speed-controller.sch]
2022-01-01 Fixed POWER_IN being a global label
    [speed-controller.sch]
2022-01-02 Added preliminary footprints
    [speed-controller.sch]
2022-01-02 Moved to KiCad 6
    [speed-controller.kicad_sch]
2022-01-02 Minor updates to values of components
    [speed-controller.kicad_sch]
2022-01-02 Created main-board blank schematic
    [main-board.kicad_pcb, main-board.kicad_sch]
2022-01-02 Added basic RP2040 schematics
    [main-board.kicad_sch, power.kicad_sch]
2022-03-18 Version 1.1.0 of main control board schematic
    [main-board.kicad_sch, network.kicad_sch, power.kicad_sch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]
2022-03-19 Moved SPI connections + increment version
    [main-board.kicad_sch, network.kicad_sch, power.kicad_sch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]
2022-03-19 Replaced USB C with micro usb
    [main-board.kicad_sch, network.kicad_sch, power.kicad_sch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]
2022-03-19 Added SD_DET to RP2040
    [main-board.kicad_sch]
2022-03-19 Fixed resistor connecting to wrong line
    [network.kicad_sch]
2022-03-19 Added resistors for LEDs
    [main-board.kicad_sch, network.kicad_sch]
2022-03-19 Incremented version number
    [main-board.kicad_sch, network.kicad_sch, power.kicad_sch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]
2022-03-19 PCB V1.0.0
    [main-board.kicad_pcb]
2022-03-19 Added images of boards
2022-03-19 Added USB + assigned footprints
    [speed-controller.kicad_sch]
2022-03-19 Changed out LM317 + increment version
    [speed-controller.kicad_sch]
2022-03-19 Added annotations
    [speed-controller.kicad_sch]
2022-03-19 Removed unnecessary components
    [speed-controller.kicad_sch]
2022-03-19 Finished V1.0.0 of driver board PCB
    [speed-controller.kicad_pcb]
2022-03-20 Created initial relay schematic
    [power.kicad_sch, relay-8.kicad_pcb, relay-8.kicad_sch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]
2022-03-20 Added 12V for relays
    [power.kicad_sch, relay-8.kicad_sch, relays.kicad_sch]
2022-03-20 Added 12V for regulator
    [power.kicad_sch, relay-8.kicad_sch, relays.kicad_sch]
2022-03-20 Changed pin connections for relay channels
    [power.kicad_sch, relay-8.kicad_sch, relays.kicad_sch]
2022-03-20 Added Tx and Rx LEDs
    [power.kicad_sch, relay-8.kicad_sch, relays.kicad_sch]
2022-03-20 Version 1.0.0 of PCB
    [relay-8.kicad_pcb]
2022-03-20 Added image of relay board

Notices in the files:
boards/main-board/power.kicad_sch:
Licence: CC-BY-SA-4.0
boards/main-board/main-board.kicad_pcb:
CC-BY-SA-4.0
